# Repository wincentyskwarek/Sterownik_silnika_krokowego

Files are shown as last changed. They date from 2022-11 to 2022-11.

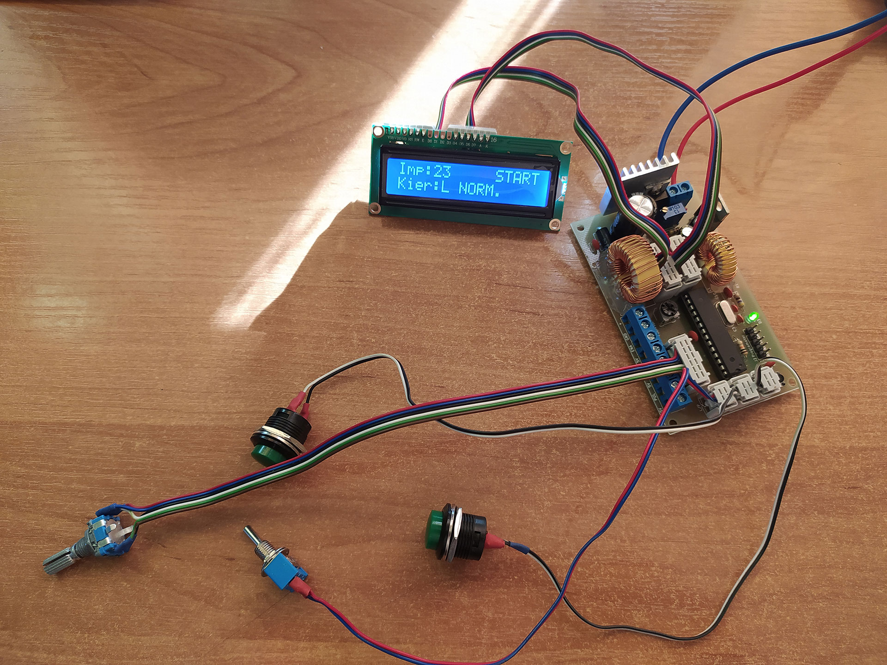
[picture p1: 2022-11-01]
zdj3.jpg

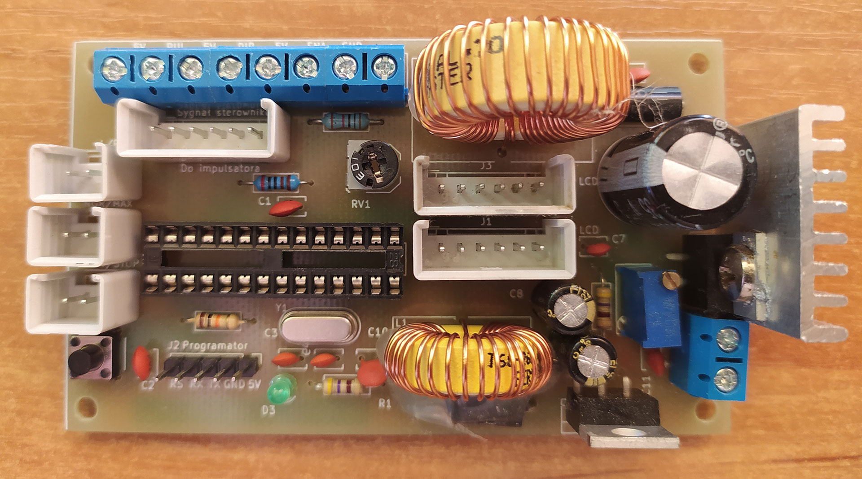
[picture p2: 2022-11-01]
zdj1.jpg

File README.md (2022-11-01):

# Sterownik_silnika_krokowego
Jakiś czas temu projektowałem sterownik silnika krokowego dwufazowego opartego na mikrokontrolerze Atmega328PU o następującej funkcjonalności:
1. Regulacja prędkości obrotowej za pomocą impulsatora od kilku do kilkuset kroków na sekundę. 
2. Możliwość zapisu ustawień prędkości po wciśnięciu przycisku impulsatora.
3. Obroty prawe-lewe zmieniane przełącznikiem.
4. Start-Stop zmieniane przełącznikiem.
5. Szybkie obroty po naciśnięciu przycisku.
6. Wyświetlacz.
7. Zasilanie z zasilacza DC 5-35 V z regulacją napięcia wyjściowego na silniki (oczywiście potrzebny sterownik np. TB6600).

Mam do odsprzedania kilka takich kompletnych sterowników, które mi zostały oraz kilka płytek drukowanych zaprojektowanych przeze mnie i wykonanych w profesjonalnym zakładzie. Rozmiar płytki (92 x 55)mm
W wolnej chwili postaram się dodać obszerniejszą dokumentację

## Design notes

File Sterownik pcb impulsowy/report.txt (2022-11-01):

Informacja: Tworznie kopii zapasowej "E:\Projekty\Sterownik_silnika_krokowego\sterownik_pcb_impulsowy\sym-lib-table" w pliku "E:\Projekty\Sterownik_silnika_krokowego\sterownik_pcb_impulsowy\rescue-backup\sym-lib-table-2022-11-01-11-12-28".
Informacja: Tworznie kopii zapasowej "E:\Projekty\Sterownik_silnika_krokowego\sterownik_pcb_impulsowy\sterownik.sch" w pliku "E:\Projekty\Sterownik_silnika_krokowego\sterownik_pcb_impulsowy\rescue-backup\sterownik-2022-11-01-11-12-28.sch".
Informacja: Tworznie kopii zapasowej "E:\Projekty\Sterownik_silnika_krokowego\sterownik_pcb_impulsowy\sterownik.pro" w pliku "E:\Projekty\Sterownik_silnika_krokowego\sterownik_pcb_impulsowy\rescue-backup\sterownik-2022-11-01-11-12-28.pro".
Informacja: Tworznie kopii zapasowej "E:\Projekty\Sterownik_silnika_krokowego\sterownik_pcb_impulsowy\sterownik-cache.lib" w pliku "E:\Projekty\Sterownik_silnika_krokowego\sterownik_pcb_impulsowy\rescue-backup\sterownik-cache-2022-11-01-11-12-28.lib".
Informacja: Tworznie kopii zapasowej "E:\Projekty\Sterownik_silnika_krokowego\sterownik_pcb_impulsowy\sterownik-rescue.lib" w pliku "E:\Projekty\Sterownik_silnika_krokowego\sterownik_pcb_impulsowy\rescue-backup\sterownik-rescue-2022-11-01-11-12-28.lib".
Informacja: Tworznie kopii zapasowej "E:\Projekty\Sterownik_silnika_krokowego\sterownik_pcb_impulsowy\sterownik-rescue.dcm" w pliku "E:\Projekty\Sterownik_silnika_krokowego\sterownik_pcb_impulsowy\rescue-backup\sterownik-rescue-2022-11-01-11-12-28.dcm".
Informacja: Dodaję bibliotekę "sterownik-rescue", plik "${KIPRJMOD}/sterownik-rescue.lib" do tabeli bibliotek projektu.
Symbol "C" zmapowany do biblioteki symboli "sterownik-rescue".
Symbol "Crystal" zmapowany do biblioteki symboli "sterownik-rescue".
Symbol "C" zmapowany do biblioteki symboli "sterownik-rescue".
Symbol "C" zmapowany do biblioteki symboli "sterownik-rescue".
Symbol "Conn_01x05_Male" zmapowany do biblioteki symboli "sterownik-rescue".
Symbol "C" zmapowany do biblioteki symboli "sterownik-rescue".
Symbol "R" zmapowany do biblioteki symboli "sterownik-rescue".
Symbol "SW_DIP_x01" zmapowany do biblioteki symboli "sterownik-rescue".
Symbol "POT" zmapowany do biblioteki symboli "sterownik-rescue".
Symbol "Conn_01x06_Male" zmapowany do biblioteki symboli "sterownik-rescue".
Symbol "Conn_01x06_Male" zmapowany do biblioteki symboli "sterownik-rescue".
Symbol "Screw_Terminal_01x02" zmapowany do biblioteki symboli "sterownik-rescue".
Symbol "Screw_Terminal_01x02" zmapowany do biblioteki symboli "sterownik-rescue".
Symbol "Screw_Terminal_01x02" zmapowany do biblioteki symboli "sterownik-rescue".
Symbol "Screw_Terminal_01x02" zmapowany do biblioteki symboli "sterownik-rescue".
Symbol "CP1" zmapowany do biblioteki symboli "sterownik-rescue".
Symbol "PWR_FLAG" zmapowany do biblioteki symboli "sterownik-rescue".
Symbol "PWR_FLAG" zmapowany do biblioteki symboli "sterownik-rescue".
Symbol "VAA" zmapowany do biblioteki symboli "sterownik-rescue".
Symbol "GNDD" zmapowany do biblioteki symboli "sterownik-rescue".
Symbol "GNDD" zmapowany do biblioteki symboli "sterownik-rescue".
Symbol "GNDD" zmapowany do biblioteki symboli "sterownik-rescue".
Symbol "GNDD" zmapowany do biblioteki symboli "sterownik-rescue".
Symbol "GNDD" zmapowany do biblioteki symboli "sterownik-rescue".
Symbol "GNDD" zmapowany do biblioteki symboli "sterownik-rescue".
Symbol "GNDD" zmapowany do biblioteki symboli "sterownik-rescue".
Symbol "GNDD" zmapowany do biblioteki symboli "sterownik-rescue".
Symbol "GNDD" zmapowany do biblioteki symboli "sterownik-rescue".
Symbol "GNDD" zmapowany do biblioteki symboli "sterownik-rescue".
Symbol "GNDD" zmapowany do biblioteki symboli "sterownik-rescue".
Symbol "GNDD" zmapowany do biblioteki symboli "sterownik-rescue".
Symbol "GNDD" zmapowany do biblioteki symboli "sterownik-rescue".
Symbol "GNDD" zmapowany do biblioteki symboli "sterownik-rescue".
Symbol "Screw_Terminal_01x06" zmapowany do biblioteki symboli "sterownik-rescue".
Symbol "ATMEGA328P-PU" zmapowany do biblioteki symboli "sterownik-rescue".
Symbol "Screw_Terminal_01x02" zmapowany do biblioteki symboli "sterownik-rescue".
Symbol "GNDD" zmapowany do biblioteki symboli "sterownik-rescue".
Symbol "LM2576" zmapowany do biblioteki symboli "sterownik-rescue".
Symbol "GNDD" zmapowany do biblioteki symboli "sterownik-rescue".
Symbol "GNDD" zmapowany do biblioteki symboli "sterownik-rescue".
Symbol "D_Schottky" zmapowany do biblioteki symboli "sterownik-rescue".
Symbol "GNDD" zmapowany do biblioteki symboli "sterownik-rescue".
Symbol "L" zmapowany do biblioteki symboli "sterownik-rescue".
Symbol "CP1" zmapowany do biblioteki symboli "sterownik-rescue".
Symbol "GNDD" zmapowany do biblioteki symboli "sterownik-rescue".
Symbol "POT" zmapowany do biblioteki symboli "sterownik-rescue".
Symbol "R" zmapowany do biblioteki symboli "sterownik-rescue".
Symbol "LM2576" zmapowany do biblioteki symboli "sterownik-rescue".
Symbol "GNDD" zmapowany do biblioteki symboli "sterownik-rescue".
Symbol "GNDD" zmapowany do biblioteki symboli "sterownik-rescue".
Symbol "D_Schottky" zmapowany do biblioteki symboli "sterownik-rescue".
Symbol "GNDD" zmapowany do biblioteki symboli "sterownik-rescue".
Symbol "L" zmapowany do biblioteki symboli "sterownik-rescue".
Symbol "CP1" zmapowany do biblioteki symboli "sterownik-rescue".
Symbol "GNDD" zmapowany do biblioteki symboli "sterownik-rescue".
Symbol "GNDD" zmapowany do biblioteki symboli "sterownik-rescue".
Symbol "C" zmapowany do biblioteki symboli "sterownik-rescue".
Symbol "C" zmapowany do biblioteki symboli "sterownik-rescue".
Symbol "GNDD" zmapowany do biblioteki symboli "sterownik-rescue".
Symbol "GNDD" zmapowany do biblioteki symboli "sterownik-rescue".
Symbol "C" zmapowany do biblioteki symboli "sterownik-rescue".
Symbol "GNDD" zmapowany do biblioteki symboli "sterownik-rescue".
Symbol "C" zmapowany do biblioteki symboli "sterownik-rescue".
Symbol "R" zmapowany do biblioteki symboli "sterownik-rescue".
Symbol "LED" zmapowany do biblioteki symboli "sterownik-rescue".
Symbol "GNDD" zmapowany do biblioteki symboli "sterownik-rescue".
Symbol "R" zmapowany do biblioteki symboli "sterownik-rescue".
Symbol "R" zmapowany do biblioteki symboli "sterownik-rescue".
Symbol "GNDD" zmapowany do biblioteki symboli "sterownik-rescue".
Symbol "Conn_01x06_Male" zmapowany do biblioteki symboli "sterownik-rescue".
Informacja: Mapowanie symboli według tabeli bibliotek zakończone!

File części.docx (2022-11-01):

Zestawienie części

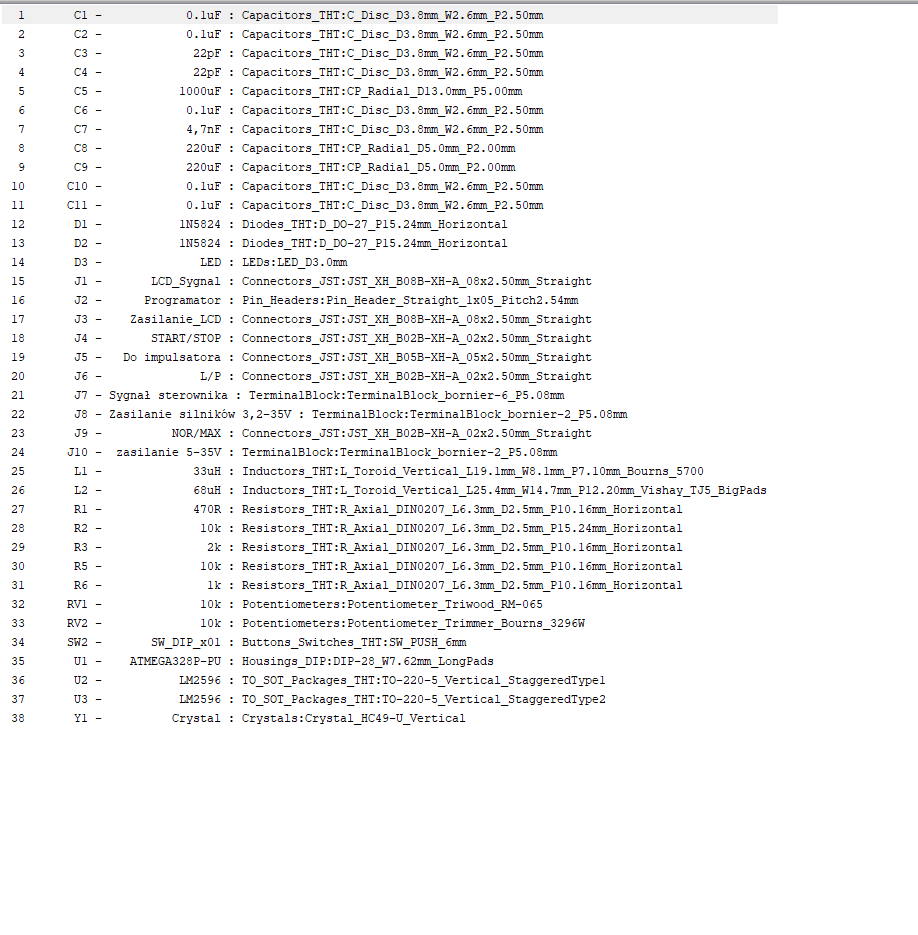
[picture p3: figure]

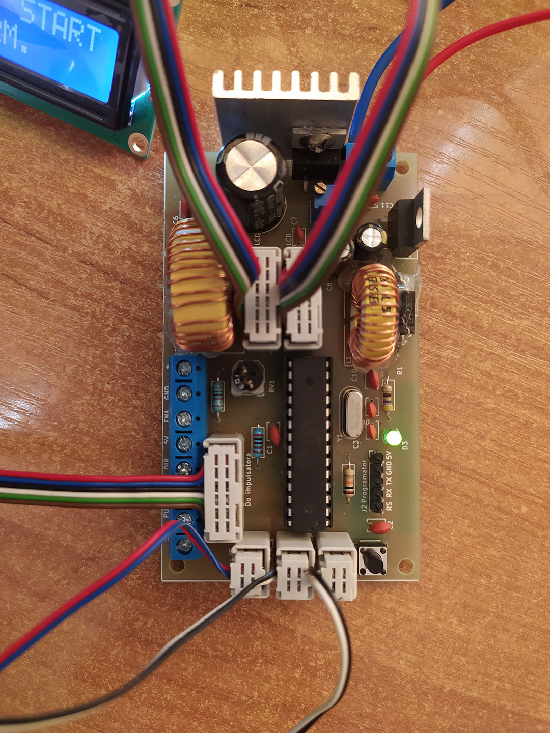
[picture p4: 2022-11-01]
zdj2.jpg

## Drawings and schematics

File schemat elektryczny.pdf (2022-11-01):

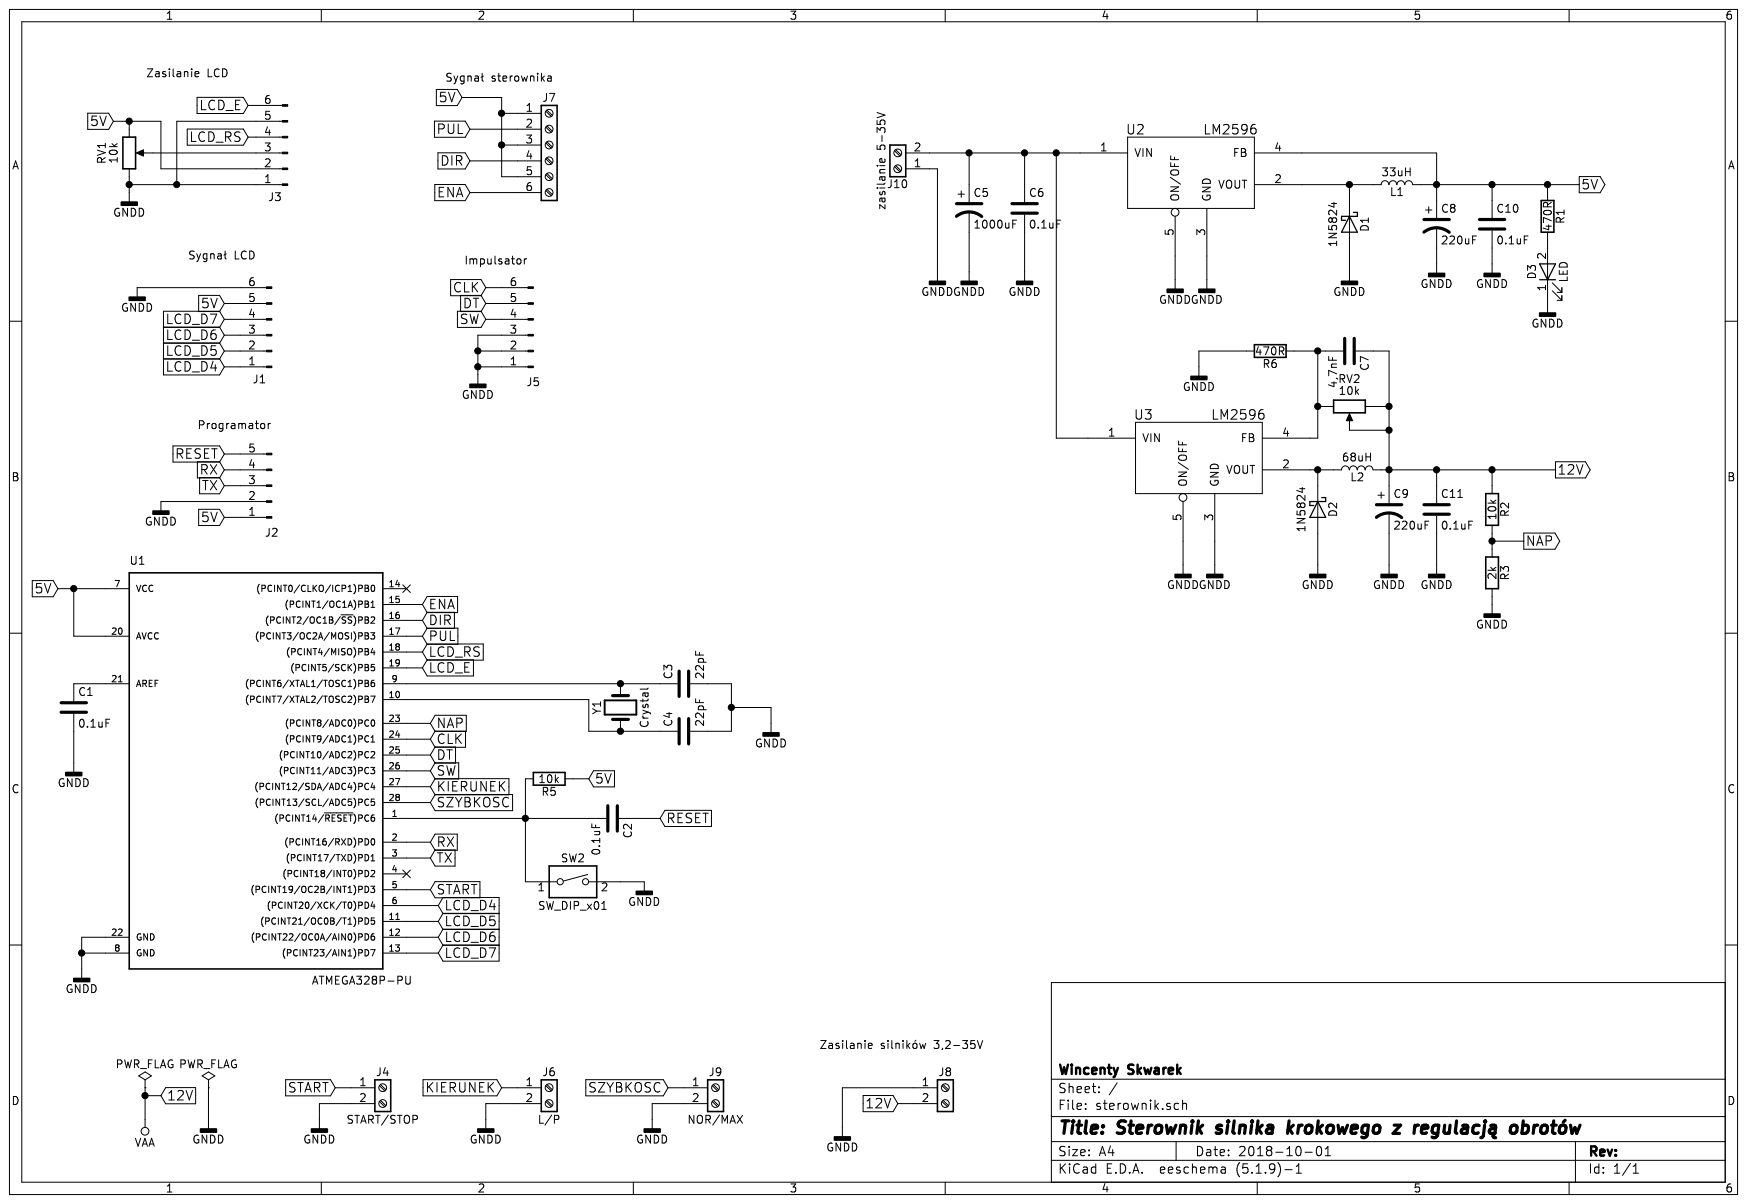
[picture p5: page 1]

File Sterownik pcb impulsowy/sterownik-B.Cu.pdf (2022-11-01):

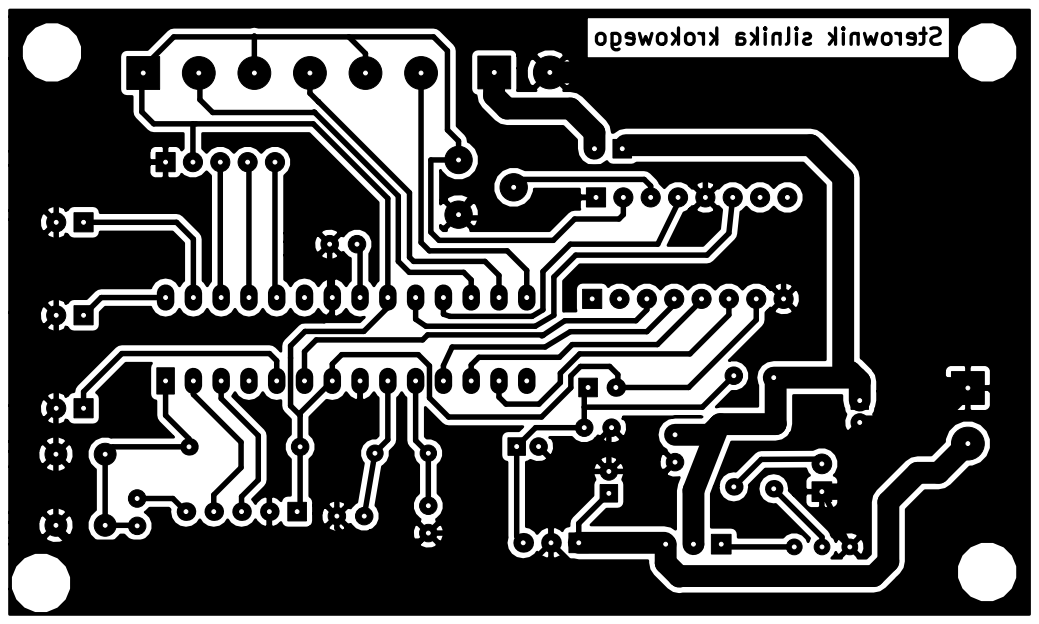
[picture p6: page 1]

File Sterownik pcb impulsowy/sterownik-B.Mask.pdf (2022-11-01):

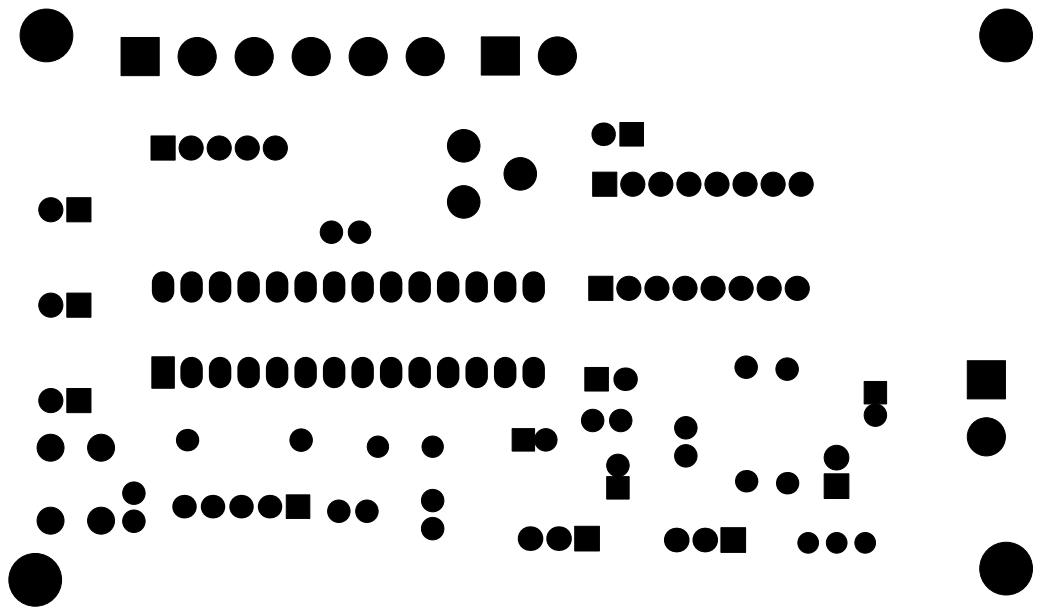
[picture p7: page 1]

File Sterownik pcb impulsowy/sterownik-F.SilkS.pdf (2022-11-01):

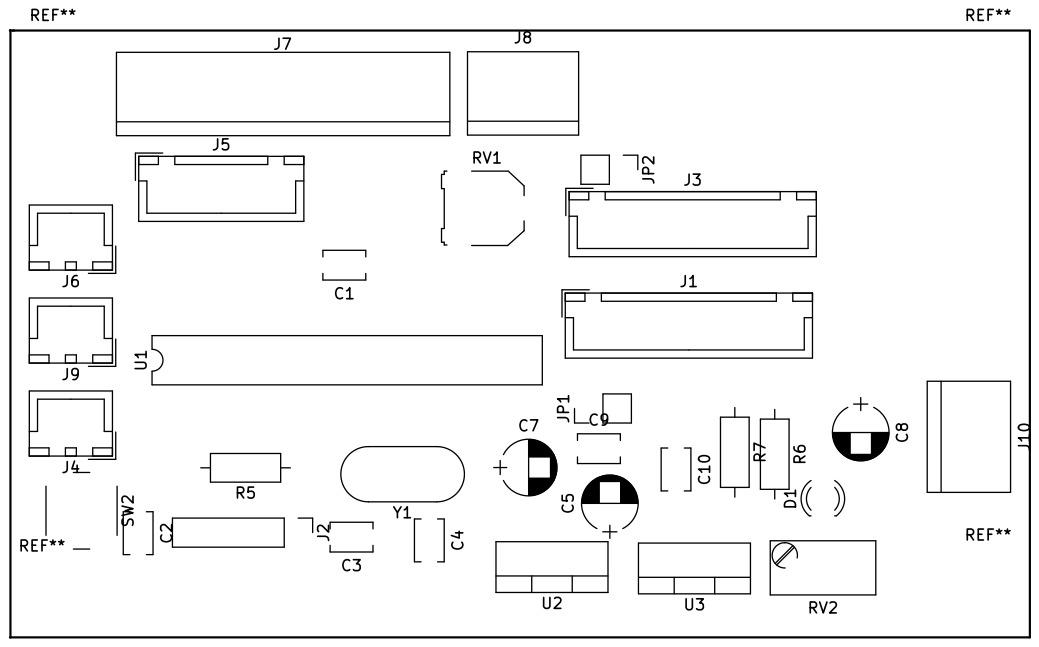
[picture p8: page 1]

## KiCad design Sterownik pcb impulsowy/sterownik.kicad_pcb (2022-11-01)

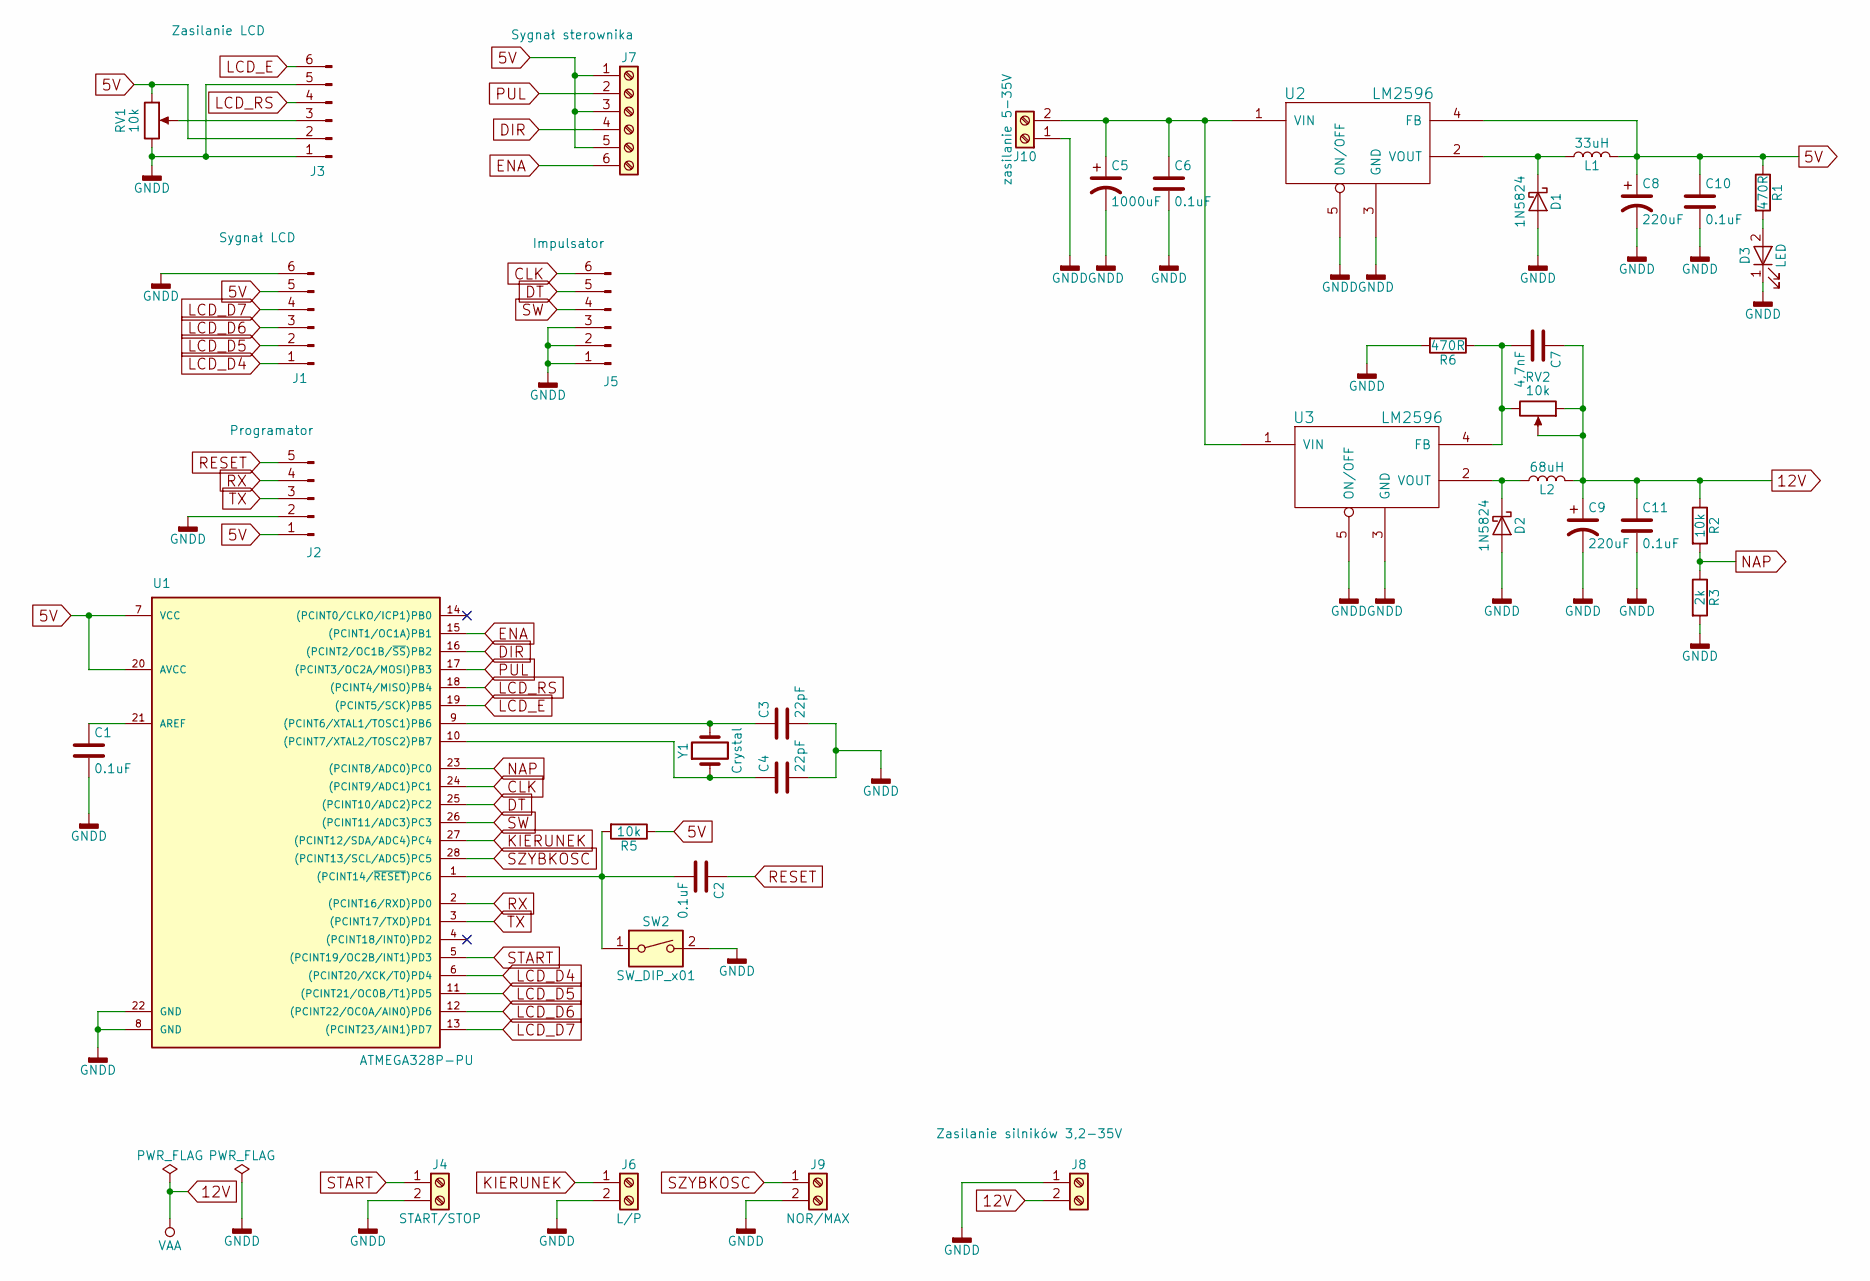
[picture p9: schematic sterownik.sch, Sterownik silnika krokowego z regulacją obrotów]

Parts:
C1, C2, C6, C10, C11: 0.1uF; C_Disc_D3.8mm_W2.6mm_P2.50mm
C3, C4: 22pF; C_Disc_D3.8mm_W2.6mm_P2.50mm
C5: 1000uF; CP_Radial_D13.0mm_P5.00mm
C7: 4,7nF; C_Disc_D3.8mm_W2.6mm_P2.50mm
C8, C9: 220uF; CP_Radial_D5.0mm_P2.00mm
D1: 1N5824; D_DO-27_P15.24mm_Horizontal
D2: 1N5824; D_DO-27_P12.70mm_Horizontal
D3: LED; LED_D3.0mm
J1: Sygnał LCD; JST_XH_B06B-XH-A_06x2.50mm_Straight
J2: Programator; Pin_Header_Straight_1x05_Pitch2.54mm
J3: Zasilanie LCD; JST_XH_B06B-XH-A_06x2.50mm_Straight
J4: START/STOP; JST_XH_B02B-XH-A_02x2.50mm_Straight
J5: Impulsator; JST_XH_B06B-XH-A_06x2.50mm_Straight
J6: L/P; JST_XH_B02B-XH-A_02x2.50mm_Straight
J7: Sygnał sterownika; TerminalBlock_bornier-6_P5.08mm
J8: Zasilanie silników 3,2-35V; TerminalBlock_bornier-2_P5.08mm
J9: NOR/MAX; JST_XH_B02B-XH-A_02x2.50mm_Straight
J10: zasilanie 5-35V; TerminalBlock_bornier-2_P5.08mm
L1: 33uH; L_Toroid_Vertical_L19.1mm_W8.1mm_P7.10mm_Bourns_5700
L2: 68uH; L_Toroid_Vertical_L25.4mm_W14.7mm_P12.20mm_Vishay_TJ5_BigPa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
R1, R6: 470R; R_Axial_DIN0207_L6.3mm_D2.5mm_P10.16mm_Horizontal
R2, R5: 10k; R_Axial_DIN0207_L6.3mm_D2.5mm_P10.16mm_Horizontal
R3: 2k; R_Axial_DIN0207_L6.3mm_D2.5mm_P10.16mm_Horizontal
RV1: 10k; Potentiometer_Triwood_RM-065
RV2: 10k; Potentiometer_Trimmer_Bourns_3296W
SW2: SW_DIP_x01; SW_PUSH_6mm
U1: ATMEGA328P-PU; DIP-28_W7.62mm_LongPads
U2: LM2596; TO-220-5_Vertical_StaggeredType1
U3: LM2596; TO-220-5_Vertical_StaggeredType2
Y1: Crystal; Crystal_HC49-U_Vertical

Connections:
5V: C8.1, C10.1, J1.5, J2.1, J3.2, J7.1, J7.3, J7.5, L1.2, R1.1, R5.1, RV1.1, U1.7 (VCC), U1.20 (AVCC), U2.4 (FB)
12V: C7.1, C9.1, C11.1, J8.2, L2.2, R2.1, RV2.1, RV2.2
CLK: J5.6, U1.24 ((PCINT9/ADC1)PC1)
DIR: J7.4, U1.16 ((PCINT2/OC1B/~SS~)PB2)
DT: J5.5, U1.25 ((PCINT10/ADC2)PC2)
ENA: J7.6, U1.15 ((PCINT1/OC1A)PB1)
GNDD: C1.2, C3.2, C4.2, C5.2, C6.2, C8.2, C9.2, C10.2, C11.2, D1.2 (A), D2.2 (A), D3.1 (K), J1.6, J2.2, J3.1, J3.5, J4.2, J5.1, J5.2, J5.3, J6.2, J8.1, J9.2, J10.1, R3.2, R6.2, RV1.3, SW2.2, U1.8 (GND), U1.22 (GND), U2.3 (GND), U2.5 (ON/OFF), U3.3 (GND), U3.5 (ON/OFF)
KIERUNEK: J6.1, U1.27 ((PCINT12/SDA/ADC4)PC4)
LCD_D4: J1.1, U1.6 ((PCINT20/XCK/T0)PD4)
LCD_D5: J1.2, U1.11 ((PCINT21/OC0B/T1)PD5)
LCD_D6: J1.3, U1.12 ((PCINT22/OC0A/AIN0)PD6)
LCD_D7: J1.4, U1.13 ((PCINT23/AIN1)PD7)
LCD_E: J3.6, U1.19 ((PCINT5/SCK)PB5)
LCD_RS: J3.4, U1.18 ((PCINT4/MISO)PB4)
NAP: R2.2, R3.1, U1.23 ((PCINT8/ADC0)PC0)
unnamed: C1.1, U1.21 (AREF)
unnamed: C2.2, R5.2, SW2.1, U1.1 ((PCINT14/~RESET~)PC6)
unnamed: C3.1, U1.9 ((PCINT6/XTAL1/TOSC1)PB6), Y1.2
unnamed: C4.1, U1.10 ((PCINT7/XTAL2/TOSC2)PB7), Y1.1
unnamed: C5.1, C6.1, J10.2, U2.1 (VIN), U3.1 (VIN)
unnamed: C7.2, R6.1, RV2.3, U3.4 (FB)
unnamed: D1.1 (K), L1.1, U2.2 (VOUT)
unnamed: D2.1 (K), L2.1, U3.2 (VOUT)
unnamed: D3.2 (A), R1.2
unnamed: J3.3, RV1.2
PUL: J7.2, U1.17 ((PCINT3/OC2A/MOSI)PB3)
RESET: C2.1, J2.5
RX: J2.4, U1.2 ((PCINT16/RXD)PD0)
START: J4.1, U1.5 ((PCINT19/OC2B/INT1)PD3)
SW: J5.4, U1.26 ((PCINT11/ADC3)PC3)
SZYBKOSC: J9.1, U1.28 ((PCINT13/SCL/ADC5)PC5)
TX: J2.3, U1.3 ((PCINT17/TXD)PD1)

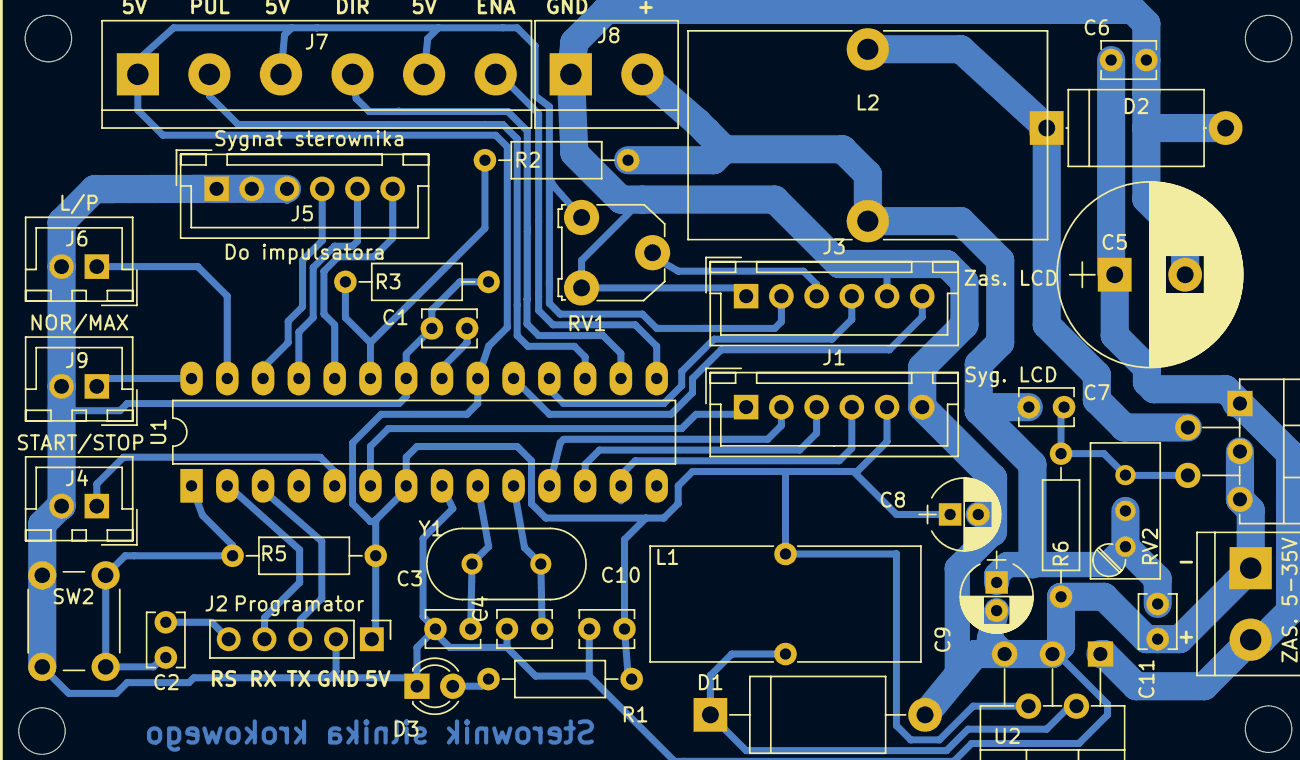
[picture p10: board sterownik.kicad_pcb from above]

Board: 2 copper layers, 38 parts (0 on the bottom side), 32 nets.

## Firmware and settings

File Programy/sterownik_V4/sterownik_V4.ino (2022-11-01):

#include <LiquidCrystal.h>
#include <EEPROM.h>

// Definicja pinów wyświetlacza
#define rs 12 
#define en 13 
#define d4 4 
#define d5 5 
#define d6 6 
#define d7 7 

// Definicja pinów sterowania TB6600
#define KR A4 //definicja pinu zmiany kierunku ruchu 
#define START 3 //definicja pinu zmiany start/stop 
#define SPEED A5 //definicja pinu zmiany NORMAL/MAX W NOWEJ WRSJI A0 -----------------------

// Definicja pinów wykonawczych TB6600
#define PUL 11 //definicja pinów pulsu
#define DIR 10 //definicja kierunków ruchu
#define ENA 9 //definicja zatrzymania wału

// definicja ustawień impulsatora
#define pinA A1  // podłączenie do CLK na KY-040
#define pinB A2  //podłączenie do DT na KY-040
#define pinSW A3 

// initializacja LCD
LiquidCrystal lcd(rs, en, d4, d5, d6, d7);

//Adres do zapisu w EEPROM
int address=0;
bool zapVisible;

int odczyt, odczytS, x=1, xS; // odczyt z potencjometru
int encoderPosCount; 
int pinALast;  
int aVal;
float vobr;
int kierunek, kierunekS;
int praca, pracaS;
int spid, spidS;
unsigned long ti, ta;
unsigned long t, tzap,czasObecnyMillis;

const int minimum=1; //dedinicja minimum szybkości (odwtotność czasu impulsu)
const int maksimum=1000; //dedinicja minimum szybkości (odwtotność czasu impulsu)
const float mnoznik=0.1398; //mnożnik do linearyzacji 0.1473

void setup() {
  // set up the LCD's number of columns and rows:
  lcd.begin(16, 2);
  // Print a message to the LCD.
  lcd.print("ElMechPlast");
  delay(2000);
  lcd.clear();
  lcd.setCursor(0, 0);
  lcd.print("Imp:");
  lcd.setCursor(0, 1);
  lcd.print("Kier:");
  pinMode (PUL, OUTPUT);
  pinMode (DIR, OUTPUT);
  pinMode (ENA, OUTPUT);
  digitalWrite(DIR,HIGH);
  digitalWrite(ENA,HIGH);
  pinMode(KR,INPUT);
  digitalWrite(KR,HIGH);
  pinMode(START,INPUT);
  digitalWrite(START,HIGH);
  pinMode(SPEED,INPUT);
  digitalWrite(SPEED,HIGH);
  
// odczyty przełączników 
  kierunek=digitalRead(KR);
  spid = digitalRead(SPEED);
  praca=digitalRead(START);
    
// Wyświetlenie START/STOP
  lcd.setCursor(11, 0);
  if (praca)
  {
      digitalWrite(ENA,HIGH);
      lcd.print("START");
  }
  else
  {
      digitalWrite(ENA,LOW);
      lcd.print("STOP ");
  }
//Wyświetlanie kierunku Prawy/Lewy
  lcd.setCursor(5, 1);
  if(kierunek)
  {
      digitalWrite(DIR,HIGH);
      lcd.print("P");
  }
  else
  { 
      digitalWrite(DIR,LOW);
      lcd.print("L ");
  }  
  
 //ustalenie prędkości startowej
  encoderPosCount=EEPROMReadInt(address);
  x=encoderPosCount;
  t=((unsigned long)(1000000.00000/x));
  vobr=mnoznik*x;
  lcd.setCursor(4, 0);
  lcd.print("      ");
  lcd.setCursor(4, 0);
  lcd.print(x);
   
// impulsator START
   pinMode (pinA,INPUT);
   digitalWrite(pinA,HIGH);
   pinMode (pinB,INPUT);
   digitalWrite(pinB,HIGH);
   pinMode (pinSW,INPUT);
   digitalWrite(pinSW,HIGH);
   /* Read Pin A
   Whatever state it's in will reflect the last position   
   */
   pinALast =digitalRead(pinA);   
  zapVisible=false;
  ti=micros(); // odczyt czasu z mikrokontrolera do generowania ruchu
  tzap=millis();// odczyt czasu z mikrokontrolera do zapisu do EEPROM
 // Serial.begin(9600);
}

void loop() {
//
  czasObecnyMillis=millis();
  if((digitalRead(pinSW)==LOW)&&(czasObecnyMillis-tzap>1000)&& (spid))
  {
    tzap=millis();
    lcd.setCursor(13, 1);
    lcd.print("ZAP");

    zapVisible=true;
    EEPROMWriteInt(address, x);
  }
  if ((czasObecnyMillis-tzap>1000) && (zapVisible))
  {
    zapVisible=false;
    lcd.setCursor(13, 1);
    lcd.print("   ");       
  }

 // Serial.println(czasObecnyMillis-tzap);
// odczyty przełączników 
  kierunek=digitalRead(KR);
  spid = digitalRead(SPEED);
  praca=digitalRead(START);
  
// Praca impulsatora
  aVal = digitalRead(pinA);
  if (aVal != pinALast) // Means the knob is rotating
     // if the knob is rotating, we need to determine direction
     // We do that by reading pin B.
  {
     if (digitalRead(pinB) != aVal)   // Means pin A Changed first - We're Rotating Clockwise
     {
       if (encoderPosCount<maksimum) encoderPosCount ++;
     }
     else // Otherwise B changed first and we're moving CCW
     {
       if (encoderPosCount>minimum) encoderPosCount--;
     }
  } 
  pinALast = aVal;

  odczyt = encoderPosCount;


// Generowanie i wyświetlanie prędkości oraz odczyt potencjometru
  if((spid!=spidS) || (odczyt!=odczytS))
  {
    lcd.setCursor(7, 1);
    if (spid==LOW)
    {
      lcd.print("MAX. ");
      x=maksimum;
    }
    else
    {
      lcd.print("NORM.");
      x=odczyt;
    }
    spidS=spid;
    odczytS=odczyt;
  }

// Włączanie i wyświetlanie pracy silnika
  if (pracaS!=praca)
  {
    lcd.setCursor(11, 0);
    if (praca)
    {
       digitalWrite(ENA,HIGH);
       lcd.print("START");
    }
    else
    {
      digitalWrite(ENA,LOW);
      lcd.print("STOP ");
    }
    pracaS=praca;
  }  
 
// Obliczanie i wyświetlanie predkości obrotowej
  if (x!=xS)
  {
    t=((unsigned long)(1000000.00000/x));
    vobr=mnoznik*x;
    lcd.setCursor(4, 0);
    lcd.print("      ");
    lcd.setCursor(4, 0);
    lcd.print(x);
    xS=x;
  }

 // Generowanie i wyświetlanie kierunku ruchu
  if (kierunek!=kierunekS)
  {
      lcd.setCursor(5, 1);
      if(kierunek)
      {
        digitalWrite(DIR,HIGH);
        lcd.print("P");
      }
      else
      { 
        digitalWrite(DIR,LOW);
        lcd.print("L");
      }    
      kierunekS=kierunek;
  }

// realizacja ruchu
      ta=micros();
      if(ta>ti)
      {
        if (ta<=ti+t)
          digitalWrite(PUL,HIGH);
        else if((ta>ti+t)&&(ta<=ti+2*t))
          digitalWrite(PUL,LOW);
        else
          ti=micros();
      }
      else
        ti=micros();

    
}
void EEPROMWriteInt(int address, int value)
{
  byte two = (value & 0xFF);
  byte one = ((value >> 8) & 0xFF);
  
  EEPROM.update(address, two);
  EEPROM.update(address + 1, one);
}
 
int EEPROMReadInt(int address)
{
  long two = EEPROM.read(address);
  long one = EEPROM.read(address + 1);
 
  return ((two << 0) & 0xFFFFFF) + ((one << 8) & 0xFFFFFFFF);
}
